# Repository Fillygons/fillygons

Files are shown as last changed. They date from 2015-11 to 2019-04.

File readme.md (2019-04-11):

# Fillygons

Small, hinged polygons to assemble polyhedrons and play with. For more information, see the [fillygons](https://fillygons.ch/) website.

## Setup

The repository needs a working [OpenScad](http://www.openscad.org/) installation to work, see [OpenSCAD Template](https://github.com/Feuermurmel/openscad-template) for instructions. Also, Python 3.4 or later is necessary.

To run, the Python project in the repository needs to be installed into a virtualenv and the virtualenv needs to be activated the Makefile needs an activated Python virtualenv with the Python project in the repository installed:

    $ python3 -m venv venv
    $ . venv/bin/activate
    (venv) $ pip install -e .
    Obtaining file:///[...]/fillygons
    Requirement already satisfied: sympy in ./venv/lib/python3.5/site-packages (from fillygons==0.0.0)
    Requirement already satisfied: mpmath>=0.19 in ./venv/lib/python3.5/site-packages (from sympy->fillygons==0.0.0)
    Installing collected packages: fillygons
      Found existing installation: fillygons 0.0.0
        Uninstalling fillygons-0.0.0:
          Successfully uninstalled fillygons-0.0.0
      Running setup.py develop for fillygons
    Successfully installed fillygons

## Compiling

Type `make -j 10 generated` to generate OpenSCAD source files for all variants. The files are placed in subdirectories of `src/variants`.

You can either open up the `.scad` files on OpenSCAD or compile them directly to _STL_ files using e.g. `make src/variants/0.2mm/4-gon/normal.scad`.

To build all _STL_ files, run `make stl`. But this will take a very long time, up to several hours.
Therefore [this repository](https://github.com/Fillygons/fillygons-stl) contains precompiled _STL_ files:

    (venv) $ make
    [generate_sources] 433 files
    [openscad] src/variants/0.2mm/3-gon/filled.stl
    [...]

## Unit tests

Some unit tests are included in the form images being rendered from of specifically generated test STL files. The rendered images are compared with expected images. Run `make test` to compare the rendered to the expected images and report any differences

## Contributing

To add new fillygon models, edit the file `fillygons/generate_sources/variants.py`.

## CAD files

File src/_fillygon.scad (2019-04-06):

include <_util.scad>

/**
Produces a single fillygon with n edges. The piece is oriented so that the outside of the polygon is on top.

Properties which change the overall shape without changing features necessary for compatibility between pieces:
    angles:
        A list of n numbers, specifying the interior angles.

    edges:
        A list of n numbers, specifying the side lengths in units of side_length_unit.

    reversed_edges:
        A list of booleans, specifying on which edges to reverse the tenons. The passed list is padded to n elements with the value false.

    filled:
        Specifies whether to close the inside of the polygon by filling in the lower side.

    filled_corners:
        Whether to cut a smaller bevel in the corners clearance region instead of using the same bevel as between the teeth.

    min_convex_angle:
        Minimum dihedral angle supported in a convex configuration.

    min_concave_angle:
        Minimum dihedral angle supported in a non-convex configuration.

    gap:
        Gap to insert between parts touching between assembled pieces to make them fit well.

Properties which change non-functional parts of the piece:
    filling_height:
        Height up to which to fill the inside of the loop.

    loop_width:
        Width of the rim along the edges of the piece connecting the teeth.

    chamfer_height:
        Width of chamfers cut into the edges and resulting edges at corners to make them less sharp/pointy.

    fn:
        Number of sides per revolution used for rounded parts.

Properties which create incompatible pieces:
    thickness:
        Thickness of the pieces.

    side_length_unit:
        Unit length of sides in mm, measured along the ideal polygon's edges. Used by default when an element of edges is set to 1.

    dedent_sphere_offset:
        Overhang of the ball dedents relative to the teeth surface.

    dedent_sphere_diameter:
        Diameter of the ball dedent spheres.

    dedent_hole_diameter:
        Diameter of the holes which accept the ball dedent spheres.

    large_teeth_width:
        Width of the large teeth.

    small_teeth_width:
        Width of the small teeth.

    small_teeth_gap:
        Gap between the small, flexible teeth.

    small_teeth_cutting_depth:
        Depth to which to cut around the small, flexible teeth.

    small_teeth_cutting_width:
        Width to cut around the small, flexible teeth.
*/
module fillygon(angles, edges, reversed_edges, filled, filled_corners, min_convex_angle, min_concave_angle, gap, filling_height, loop_width, chamfer_height, fn, thickness, side_length_unit, dedent_sphere_offset, dedent_sphere_diameter, dedent_hole_diameter, large_teeth_width, small_teeth_width, small_teeth_gap, small_teeth_cutting_depth, small_teeth_cutting_width) {
    $fn = fn;

	module reverse() {
		translate([$side_length / 2, 0, 0]) {
			scale([$reversed_edge ? -1 : 1, 1, 1]) {
				translate([-$side_length / 2, 0, 0]) {
					children();
				}
			}
		}
	}
	
	module trace(intersect = false) {
		module more(i) {
			if (i < len(angles) - 1) {
				translate([side_length_unit * edges[i], 0, 0]) {
					rotate(180 - angles[i + 1]) {
						tail(i + 1) {
							children();
						}
					}
				}
			}
		}
		
		module tail(i) {
			// Ugly hack to pass the angle of the previous corner into the child modules.
			$corner_angle = angles[i];
			$reversed_edge = i < len(reversed_edges) && reversed_edges[i];
			$side_length = side_length_unit * edges[i];

			if (intersect) {
				intersection() {
					reverse() {
						children();
					}
					
					more(i) {
						children();
					}
				}
			} else {
				union() {
					reverse() {
						children();
					}
					
					more(i) {
						children();
					}
				}
			}
		}
		
		tail(0) {
			union() {
				children();
			}
		}
	}
	
	// Calculates the x-position of the chamfer for an edge produced by 2 planes with distance d from the origin and angles a1 and a2.
	function chamfer_pos(d, a1, a2) = abs(a1 - 90) * PI / 180 < 1 / 1000 && abs(a2 - 90) * PI / 180 < 1 / 1000 ? d : (chamfer_height * (cos(a1 - a2) + cos(a1 + a2)) / 2 + d * (cos(a1) + cos(a2))) / sin(a1 + a2);
	
	// Calculates the x-position of the chamfer for a corner produced by 2 planes with distances d from the origin and internal angle a.
	function corner_chamfer_pos(d, a) = chamfer_pos(d, a / 2, a / 2);

	// These are, in order, the left and right edges of the first and second instance of the large and small teeth. The last element is the right end of the cutting which complements the first tooth. All elements are relative to the end of the left clearance region.
	positions = accumulate_list([
		0,
		large_teeth_width,
		2 * small_teeth_width + small_teeth_gap,
		large_teeth_width,
		large_teeth_width,
		small_teeth_width,
		small_teeth_gap,
		small_teeth_width,
		large_teeth_width]);

	// List which specifies, for each entry in the positions list, in which direction gap / 2 should be added, if at all.
	gaps = [1, -1, 1, -1, 1, 0, 0, -1, 1];

	// Length on each end of an edge where no teeth are placed.
	function corner_clearance(side_length) = (side_length - positions[len(positions) - 1]) / 2;

	function dir(pos) = 1 - pos % 2 * 2;
	function pos(pos, side_length) = corner_clearance(side_length) + positions[pos] + gaps[pos] * gap / 2;
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

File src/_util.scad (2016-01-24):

_inf = 1e4;
_inf2 = 2 * _inf;

module extrude(min = -_inf, max = _inf) {
	translate([0, 0, min]) {
		linear_extrude(max - min) {
			children();
		}
	}
}

module sector_2d(xmin = -_inf, xmax = _inf, ymin = -_inf, ymax = _inf) {
	translate([xmin, ymin]) {
		square([xmax - xmin, ymax - ymin]);
	}
}

module sector_3d(xmin = -_inf, xmax = _inf, ymin = -_inf, ymax = _inf, zmin = -_inf, zmax = _inf) {
	translate([xmin, ymin, zmin]) {
		cube([xmax - xmin, ymax - ymin, zmax - zmin]);
	}
}

// Return a list of all integers not smaller than start but smaller than end. The start can be omitted and defaults to 0.
function range(start, end) = end == undef ? range(0, start) : (start < end ? [start:end - 1] : []);

// Return a list of elements from positions range(start, end) in list v.
function slice(v, start, end) = [for (i = range(start, end)) v[i]];

// Return the sum of the elements of list v.
function sum_list(v, i = 0) = i < len(v) ? v[i] + sum_list(v, i + 1) : 0;

// Return a new list, where each element is the sum of the element up to the element at the same position in list v.
function accumulate_list(v) = [for (i = range(len(v))) sum_list(slice(v, 0, i + 1))];

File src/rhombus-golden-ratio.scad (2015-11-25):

use <_fillygon.scad>

render() fillygon([atan(2), 180 - atan(2), atan(2)]);

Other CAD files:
src/rhombus.scad

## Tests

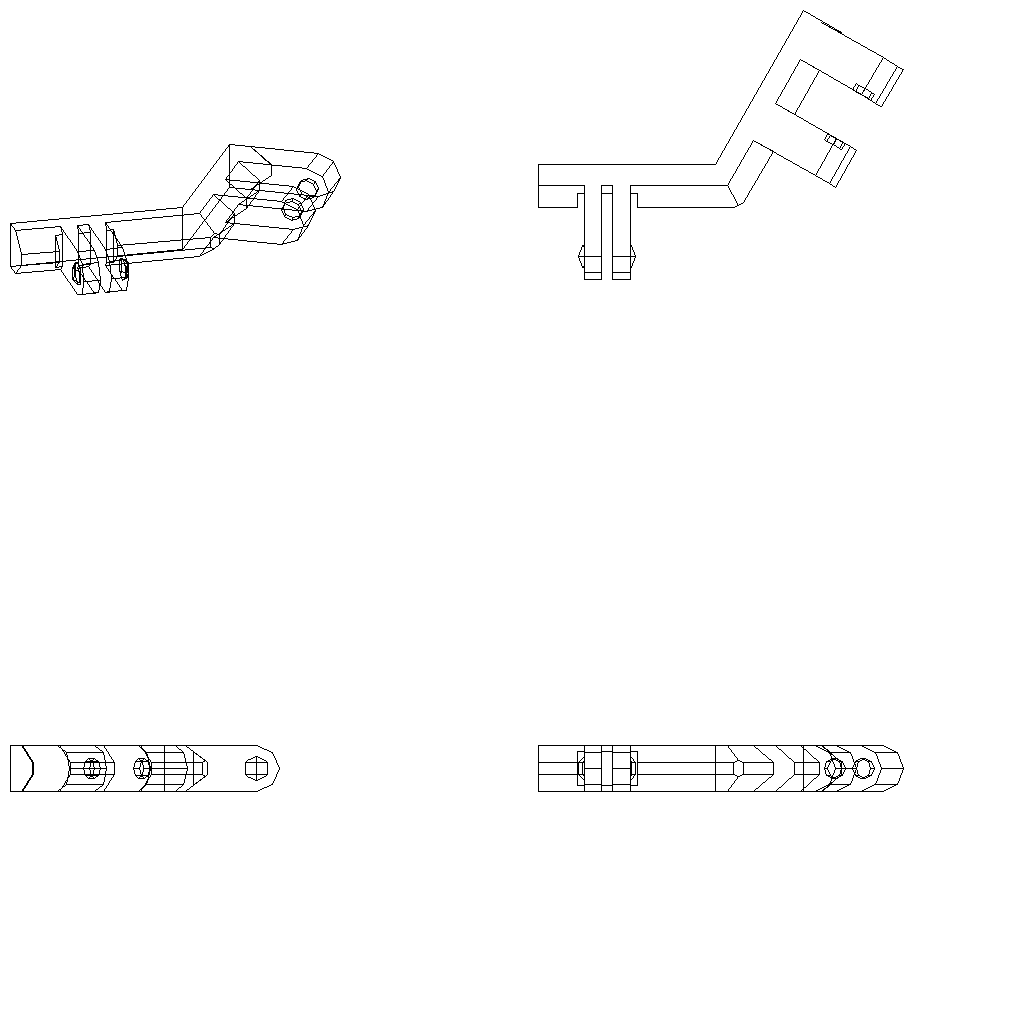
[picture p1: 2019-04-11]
src/tests/3-expected.png

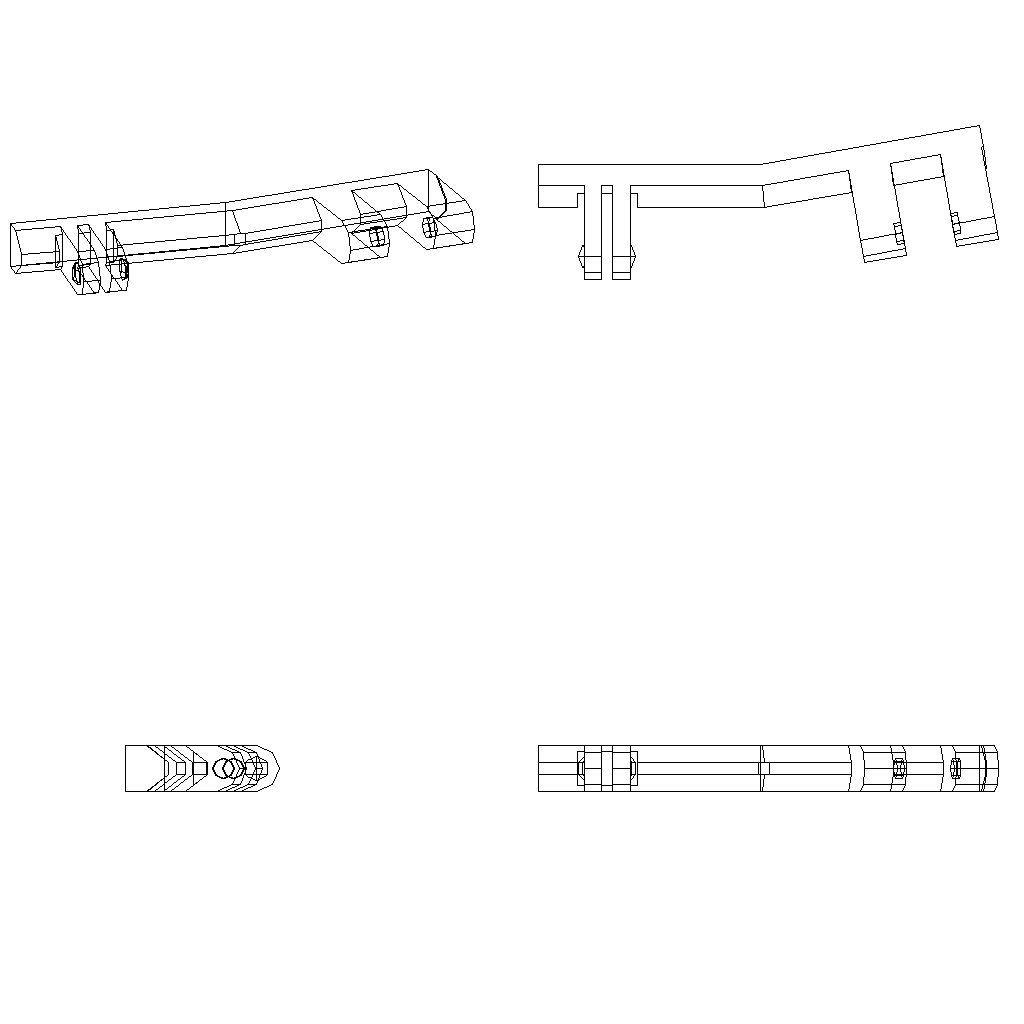
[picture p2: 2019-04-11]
src/tests/4-expected.png

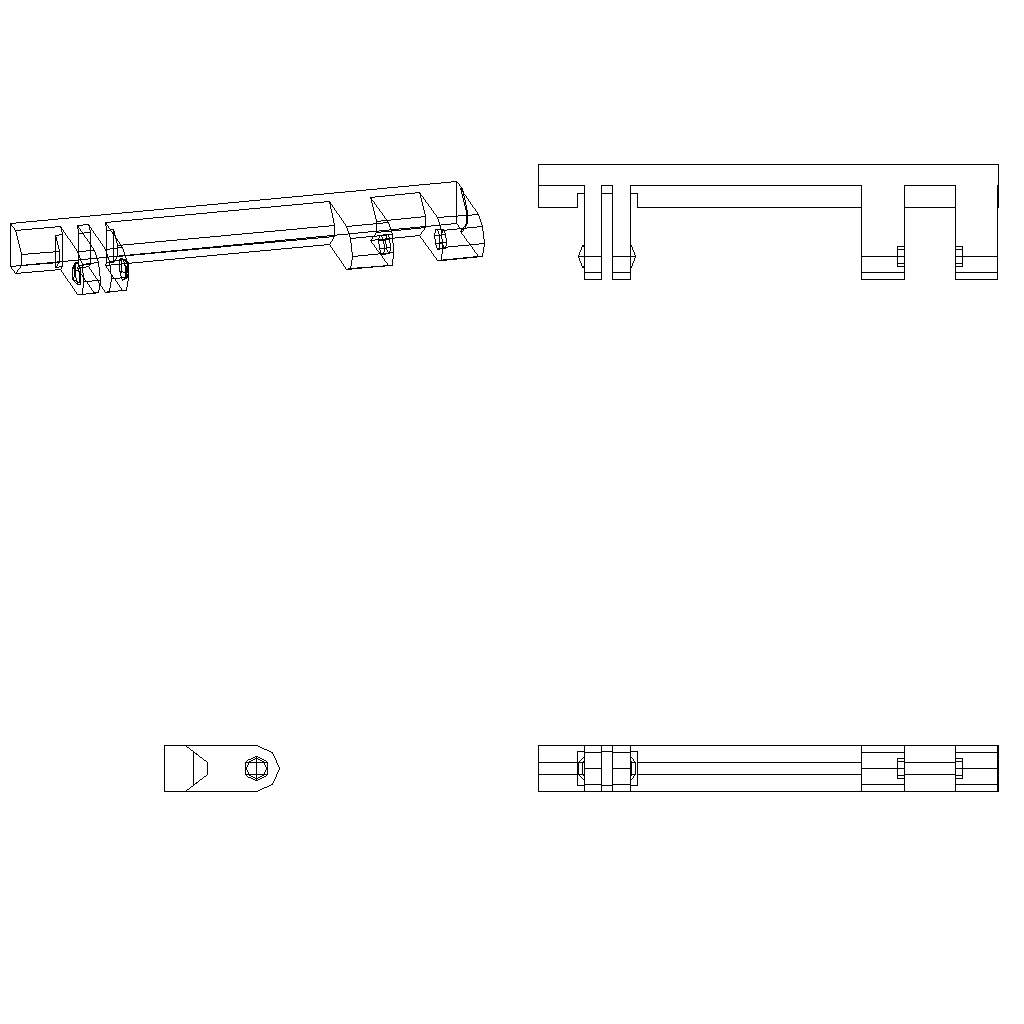
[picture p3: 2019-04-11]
src/tests/5-expected.png

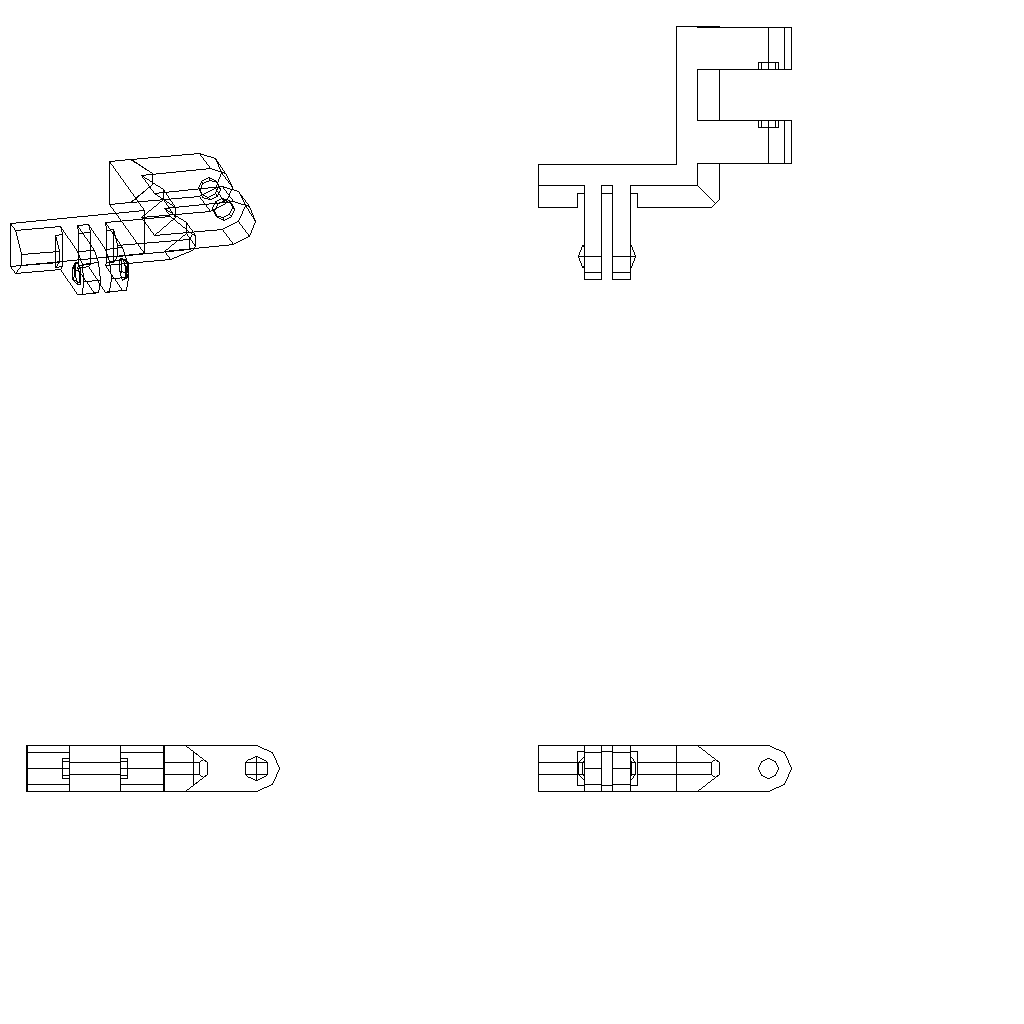
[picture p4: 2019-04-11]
src/tests/2-expected.png

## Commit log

2014-11-27 First version of the template project.
    [example.scad]
2014-11-28 Removed example files from project template.
    [example.scad]
2014-12-12 Added more example files to showcase dependency tracking.
    [_settings.scad, example.scad, example_1.scad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]
2014-12-12 Revert "Added more example files to showcase dependency tracking."
    This reverts commit b69003800917a93c5c2b240ede6f83b80f1095cc.
    [_settings.scad, example_1.scad, example_2.scad]
2014-12-21 Workaround for OpenSCAD sometimes writing an empty STL file when it crashes.
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2015-03-21 dxf export: Use different colors for layers.
    With this change, different colors are assigned to shapes. Shapes on the same layer get the same color. This allows them to be grouped by color by software that doesn’t support layers (e.g. Lasercut 5.3).
2015-07-12 support: Workaround for tempdir on different mount.
    This adds a workaround for setups where the user has checked out the project on a different mount point than where the temporary directory is located.
2015-09-15 Revert "support: Workaround for tempdir on different mount."
    This reverts commit 3d21efd4897053e760ad7f4ce14a5482f66e858c.
2015-09-15 New workaround for temp dir on different device.
    Currently, on setups where the project dir is on a different file system as the system temporary directory, a temporary directory is instead created on the project dir. This is not very nice.
    With this change, we still create temporary files in the system temporary directory but copy instead of move files from and to the temporary directory, if necessary, which solves the problems.
2015-09-15 Prevent Python stack trace when an external command failed.
    This catches the OSError thrown by the subprocess module and wraps it so that in the end only an error message is printed, explaining which command failed.
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2015-10-01 Don’t mask exceptions when process.kill() fails.
2015-11-09 First version with a lot of missing details.
    [3-gon.scad, 4-gon.scad, 5-gon.scad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]
2015-11-09 Improverd version without trimmed teeth at corners.
    [_fillygon.scad, _util.scad]
2015-11-09 Use exact corner clearing for optimal teeth on triangle.
    [_fillygon.scad]
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2015-11-09 Added test file with combined parts.
    [combine-test.scad]
2015-11-09 Use original polygon shape at corners.
    [_fillygon.scad]
2015-11-09 Implemented gaps between shapes.
    [_fillygon.scad]
2015-11-09 Fixed bleeding of teeth into adjacent edges.
    [_fillygon.scad]
2015-11-09 Larger gap so that parts fit together without --force.
    [_fillygon.scad]
2015-11-09 Fixed mixup of invert parameter.
    [_fillygon.scad]
2015-11-09 Implemented sphere parts of dedents.
    [_fillygon.scad]
2015-11-09 Upped circle quality for print.
    [_fillygon.scad]
2015-11-09 Implemented hole part of dedents.
    [_fillygon.scad]
2015-11-09 Remove part at bottom to allow acute angles.
    [_fillygon.scad]
2015-11-09 Moved gap on clearance to teeth_region().
    [_fillygon.scad, _util.scad]
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2015-11-09 Cut away part on clearance to allow rotating joined polygons.
    [_fillygon.scad]
2015-11-10 Added a test file for a partial tetrahedron.
    [test-combined.scad, test-tetrahedron.scad]
2015-11-10 Flip printed parts upside down because of overhangs.
    [3-gon.scad, 4-gon.scad, 5-gon.scad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]
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2015-11-10 Restructured decent code to remove redundant code.
    [_fillygon.scad]
2015-11-10 Decreased minimal dihedral angle to τ / 6.
    [_fillygon.scad]
2015-11-10 Smaller overhang of the ball dedent sphere.
    [_fillygon.scad]
2015-11-10 Reversed direction of ball decent interfaces.
    [_fillygon.scad]
2015-11-10 Automatically calculate dedent directions.
    [_fillygon.scad]
2015-11-11 Refactored code to prevent duplicate code.
    [_fillygon.scad]
2015-11-11 Extracted dedent balls from teeth_region().
    [_fillygon.scad]
2015-11-11 Extracted dedent holes from teeth_region().
    [_fillygon.scad]
2015-11-11 Extracted clearances from teeth_region().
    [_fillygon.scad]
2015-11-11 Removed almost all of the magic!
    This also removed some of the correctness, though.
    [_fillygon.scad]
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2015-11-11 Moved calls to trace() to the main function.
    [_fillygon.scad]
2015-11-12 Refactored complete module to remove all traces of magic.
    [_fillygon.scad]
2015-11-12 Simplified new code a bit.
    [_fillygon.scad]
2015-11-12 Optimized and removed some redundant code.
    [_fillygon.scad]
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2015-11-12 Workaround for dedent spheres not being connected.
    [_fillygon.scad]
2015-11-12 Generate regular polygons up to the octagon.
    [3-gon.scad, 4-gon.scad, 5-gon.scad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]
2015-11-13 Replaced open tetrahedron with shape with just 2 faces.
    [test-combined-2.scad, test-tetrahedron.scad]
2015-11-13 Reduced minimum angle because of the 4-sided pyramid.
    [_fillygon.scad]
2015-11-13 Added a bit of documentation.
    [_fillygon.scad]
2015-11-22 Hacked a lot of stuff to remove a small chamfer.
    [_fillygon.scad]
2015-11-22 First test with elastic dedents.
    [_fillygon.scad]
2015-11-22 Added another test part.
    [test-monogon.scad]
2015-11-22 Added second version with elastic dedents.
    [_fillygon.scad]
2015-11-22 Remove random parts at infinity.
    [_fillygon.scad]
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2015-11-23 Moved test shapes to separate directory.
    [test-combined-2.scad, test-combined.scad, test-monogon.scad]
2015-11-23 Removed for print because shape is now symmetric.
    [rhombus.scad]
2015-11-23 Fixed included paths in moved tests.
    [test-combined-2.scad, test-combined.scad, test-monogon.scad]
2015-11-23 Fixed length of monogon.
    [test-monogon.scad]
2015-11-23 Hardcoded tooth positions instead of dynamically calculating them.
    [_fillygon.scad]
2015-11-23 Slightly smaller minimum angle to allow pentagonal pyramid.
    [_fillygon.scad]
2015-11-23 Implemented cuttings for flexible dedent teeth.
    [_fillygon.scad]
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2015-11-25 Added rhombus with diagonals ratio of the golden ratio.
    [rhombus-golden-ratio.scad]
2016-01-11 Fixed first edge being calculated twice.
    [_fillygon.scad]
2016-01-11 Implemented reversing of polygons.
    [_fillygon.scad]
2016-01-11 Added 3-gon with reversed edge.
    [3-gon-reversed.scad]
2016-01-14 Fillygons with multiple side length
    [_fillygon.scad]
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2016-01-15 Added miters to the edges.
    [_fillygon.scad]
2016-01-15 Use generalised repeated-edge code for all regular pieces.
    [_fillygon.scad]
2016-01-16 Revert "Added miters to the edges."
    This reverts commit 3018df27495eff2f99e6df322a5c972d9a7a43c0.
    By bad, this commit was not ready yet.
    [_fillygon.scad]
2016-01-16 Added fillings to the inside of the pieces.
    [_fillygon.scad]
2016-01-16 Added and fixed some comments.
    [_fillygon.scad]
2016-01-16 Removed a useless operator.
    [_fillygon.scad]
2016-01-16 Pass options using keywords.
    [3-gon-reversed.scad, _fillygon.scad]
2016-01-16 Add option to fill the insides of the pieces.
    [3-gon-filled.scad, _fillygon.scad]
2016-01-16 Generate filled variants automatically.
    [3-gon-filled.scad]
2016-01-16 Move custom shapes to separate directory.
    [3-gon-reversed.scad, rhombus-golden-ratio.scad, rhombus.scad]
2016-01-16 Also generate inverted tiles.
    [3-gon-reversed.scad]
2016-01-16 Also generate files with custom angles.
    [_rhombus-golden-ratio.scad, _rhombus.scad, rhombus-golden-ratio.scad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]
2016-01-16 Generate different versions for gap widths.
    [_fillygon.scad]
2016-01-16 Also bevel the vertical edges on the corners.
    [_fillygon.scad, _util.scad]
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2016-01-18 Adapted edge chamfers to asymmetrical angles.
    [_fillygon.scad]
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2016-01-18 Re-implemented corner chamfers for filled corners.
    [_fillygon.scad]
2016-01-18 Fixed bevel and chamfer terminology mixup.
    [_fillygon.scad]
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2016-01-18 Fixed setting which was accidentally changed.
    [_fillygon.scad]
2016-01-18 Moved tuneable values to a separate file to make it harder to commit changes to them accidentally.
    [_fillygon.scad, _settings.scad]
2016-01-21 Pass all new parameters from regular_fillygon() to fillygon().
    [_fillygon.scad, test-options.scad]
2016-01-21 Fixed chamfers when both dihedral angles are τ / 4.
    [_fillygon.scad]
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2016-01-24 Fixed teeth moving when gap was changed.
    This changes the way the size of the teeth are specified and calculated and fixes a problem where the teeth would not just change their width but also their position when the gap was changed.
    [_fillygon.scad, _settings.scad]
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2016-01-24 Fixed dents in filled corners.
    [_fillygon.scad]
2016-01-24 Fixed corner chamfers on reversed edges.
    [_fillygon.scad]
2016-02-04 Function to generate angle list for regular fillygons.
    [_fillygon.scad]
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2016-02-21 Adjusted parameters for very tight fit.
    [_settings.scad]
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2016-03-19 Removed broken test file.
    [test-dedents-0.1mm.scad]
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2016-03-26 add rhombus to make a spiral with four sides
    [_rhombus_quad.scad]
2016-03-27 Removed broken test files.
    [test-dedents.scad]
2016-03-27 Fixed broken test case.
    [test-options.scad]
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2016-08-02 Renamed flat hexagons for shorter names.
    [_6-gon-flat-109.scad, _6-gon-flat-117.scad, _6-gon-flat-63.scad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]
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2018-01-10 Automatically determine the length of the last edge
    [_fillygon.scad, _util.scad]
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2018-01-19 Fix some typos
    [_fillygon.scad, _settings.scad]
2018-01-19 Defined all variables for fillygon() in Python code
    [_fillygon.scad, _settings.scad]
2019-04-04 Fix missing side_length_unit in fillygon() parameter list
    [_fillygon.scad]
2019-04-11 Infrastructure to render test files as wireframe images
    [4-gon.scad]
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
